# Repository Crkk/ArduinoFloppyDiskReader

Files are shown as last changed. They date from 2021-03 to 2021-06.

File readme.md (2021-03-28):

# Arduino Powered Amiga Floppy Disk Reader and Writer
Created by Robert Smith @RobSmithDev

Hardware design added by @Crkk

# What is it?
This project uses an Arduino to interface with a floppy disk drive and communicate with a PC in order to recover the data from Amiga formatted AmigaDOS disks.
It also allows you to write a backed up ADF file back onto a floppy disk!

# ArduinoFloppyReader
This Visual Studio 2017 project contains two applications, a command line, and a Windows dialog based application

# FloppyDriverController.sketch
This is the Ardunio source code/sketch

# AVR Firmware
If you want to use the AVR directly instead of within the Arduino environment, then jump to [https://github.com/jtsiomb/usbamigafloppy] where John Tsiombikas has ported the code.

# Help and Instructions 
For further details including how to wire this up please visit [http://amiga.robsmithdev.co.uk]

# Whats changed?
V2.2 Fixed 99% of checksum errors when writing by erasing the track first
V2.1 Diagnostics and potential write bug fixed
V2.0 Disk reading has been vastly improved and you can now also write disks!
V1.0 Initial release, can read disks fairly well

# Licence
This entire project is available under the GNU General Public License v3 licence.  See licence.txt for more details.

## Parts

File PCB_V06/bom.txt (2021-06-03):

100 nF 50V	C1, C2, C6		0603
1 kOhm		R1, R2			0603
220 Ohm		R3, R4			0603
22 uF 25V	C3, C4, C5, C7, C8, C9	0805
ATMEGA328P	U1			TQFP32
FT232RL		IC1			SSOP28
16MHz resonator Y1			3.2x1.3
Mini USB	USB			B-SMT
Green LED	D1			5mm
Red LED		D2			5mm
Header		FLOPPY			34pin male
FPC conn	FLOPPY_26		26pin 1mm

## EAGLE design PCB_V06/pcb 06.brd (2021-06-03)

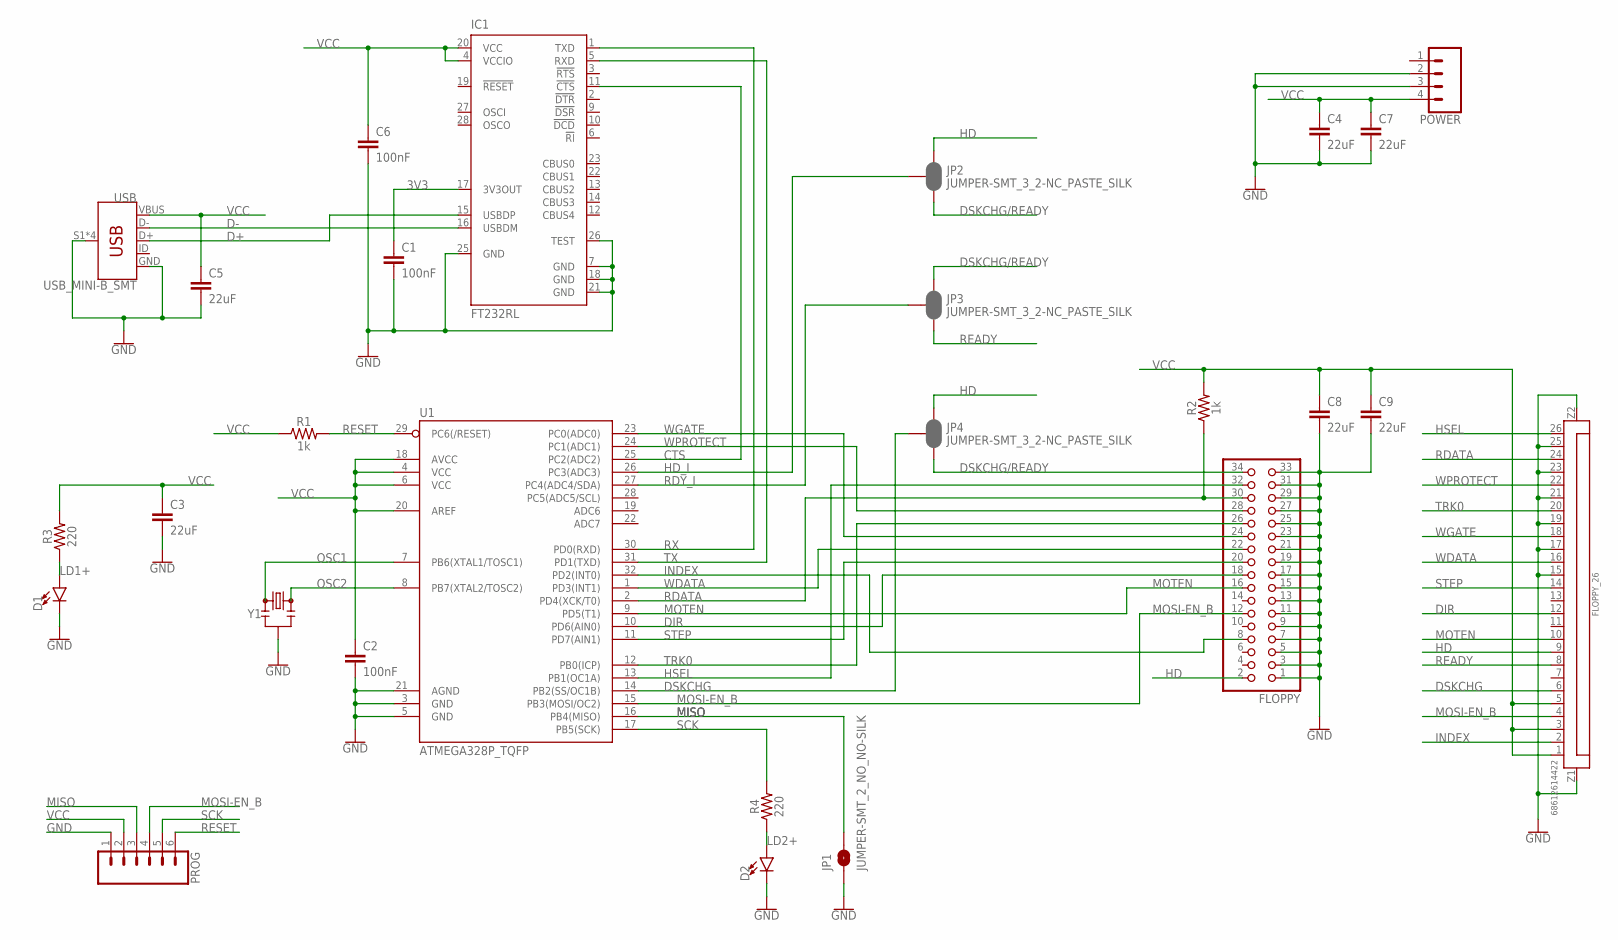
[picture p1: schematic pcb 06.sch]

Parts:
C1, C2, C6: 100nF; 0603
C3, C4, C5, C7, C8, C9: 22uF; C0805
D1, D2: LED5MM; LED_5MM
FLOPPY: PINHD-2X17_2.54-90°; 2X17/90
FLOPPY_26: 68612614422
IC1: FT232RL; SSOP28
JP1: JUMPER-SMT_2_NO_NO-SILK; SMT-JUMPER_2_NO_NO-SILK
JP2, JP3, JP4: JUMPER-SMT_3_2-NC_PASTE_SILK; SMT-JUMPER_3_2-NC_PASTE_SILK
POWER: CONN_04; 1X04
PROG: CONN_06SILK_FEMALE_PTH; 1X06
R1, R2: 1k; 0603
R3, R4: 220; 0603
U1: ATMEGA328P_TQFP; TQFP32-08
USB: USB_MINI-B_SMT; USB-MINIB
Y1: RESONATORSMD-3.2X1.3; RESONATOR-SMD-3.2X1.3

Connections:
3V3: C1.1, IC1.17 (3V3OUT)
CTS: IC1.11 (!CTS), U1.25 (PC2(ADC2))
D+: IC1.15 (USBDP), USB.D+
D-: IC1.16 (USBDM), USB.D-
DIR: FLOPPY.18, FLOPPY_26.12, U1.10 (PD6(AIN0))
DSKCHG: FLOPPY_26.6, JP4.2, U1.14 (PB2(SS/OC1B))
DSKCHG/READY: FLOPPY.34, JP2.3, JP3.1, JP4.3
GND: C1.2, C2.2, C3.2, C4.2, C5.2, C6.2, C7.2, C8.2, C9.2, D1.K (C), D2.K (C), FLOPPY.1, FLOPPY.3, FLOPPY.5, FLOPPY.7, FLOPPY.9, FLOPPY.11, FLOPPY.13, FLOPPY.15, FLOPPY.17, FLOPPY.19, FLOPPY.21, FLOPPY.23, FLOPPY.25, FLOPPY.27, FLOPPY.29, FLOPPY.31, FLOPPY.33, FLOPPY_26.15, FLOPPY_26.17, FLOPPY_26.19, FLOPPY_26.21, FLOPPY_26.23, FLOPPY_26.25, FLOPPY_26.Z1, FLOPPY_26.Z2, IC1.7 (GND), IC1.18 (GND), IC1.21 (GND), IC1.25 (GND), IC1.26 (TEST), JP1.1, POWER.2, POWER.3, PROG.1, U1.3 (GND), U1.5 (GND), U1.21 (AGND), USB.GND, USB.S1 (SHIELD), USB.S2 (SHIELD), USB.S3 (SHIELD), USB.S4 (SHIELD), Y1.2
HD: FLOPPY.2, FLOPPY_26.9, JP2.1, JP4.1
HD_I: JP2.2, U1.26 (PC3(ADC3))
HSEL: FLOPPY.32, FLOPPY_26.26, U1.13 (PB1(OC1A))
INDEX: FLOPPY.8, FLOPPY_26.2, U1.32 (PD2(INT0))
LD1+: D1.A, R3.1
LD2+: D2.A, R4.1
MISO: JP1.2, PROG.3, U1.16 (PB4(MISO))
MOSI-EN_B: FLOPPY.12, FLOPPY_26.4, PROG.4, U1.15 (PB3(MOSI/OC2))
MOTEN: FLOPPY.16, FLOPPY_26.10, U1.9 (PD5(T1))
OSC1: U1.7 (PB6(XTAL1/TOSC1)), Y1.1
OSC2: U1.8 (PB7(XTAL2/TOSC2)), Y1.3
RDATA: FLOPPY.30, FLOPPY_26.24, R2.1, U1.2 (PD4(XCK/T0))
RDY_I: JP3.2, U1.27 (PC4(ADC4/SDA))
READY: FLOPPY_26.8, JP3.3
RESET: PROG.6, R1.2, U1.29 (PC6(/RESET))
RX: IC1.1 (TXD), U1.30 (PD0(RXD))
SCK: PROG.5, R4.2, U1.17 (PB5(SCK))
STEP: FLOPPY.20, FLOPPY_26.14, U1.11 (PD7(AIN1))
TRK0: FLOPPY.26, FLOPPY_26.20, U1.12 (PB0(ICP))
TX: IC1.5 (RXD), U1.31 (PD1(TXD))
VCC: C2.1, C3.1, C4.1, C5.1, C6.1, C7.1, C8.1, C9.1, FLOPPY_26.1, FLOPPY_26.3, FLOPPY_26.5, IC1.4 (VCCIO), IC1.20 (VCC), POWER.4, PROG.2, R1.1, R2.2, R3.2, U1.4 (VCC), U1.6 (VCC), U1.18 (AVCC), U1.20 (AREF), USB.VBUS
WDATA: FLOPPY.22, FLOPPY_26.16, U1.1 (PD3(INT1))
WGATE: FLOPPY.24, FLOPPY_26.18, U1.23 (PC0(ADC0))
WPROTECT: FLOPPY.28, FLOPPY_26.22, U1.24 (PC1(ADC1))

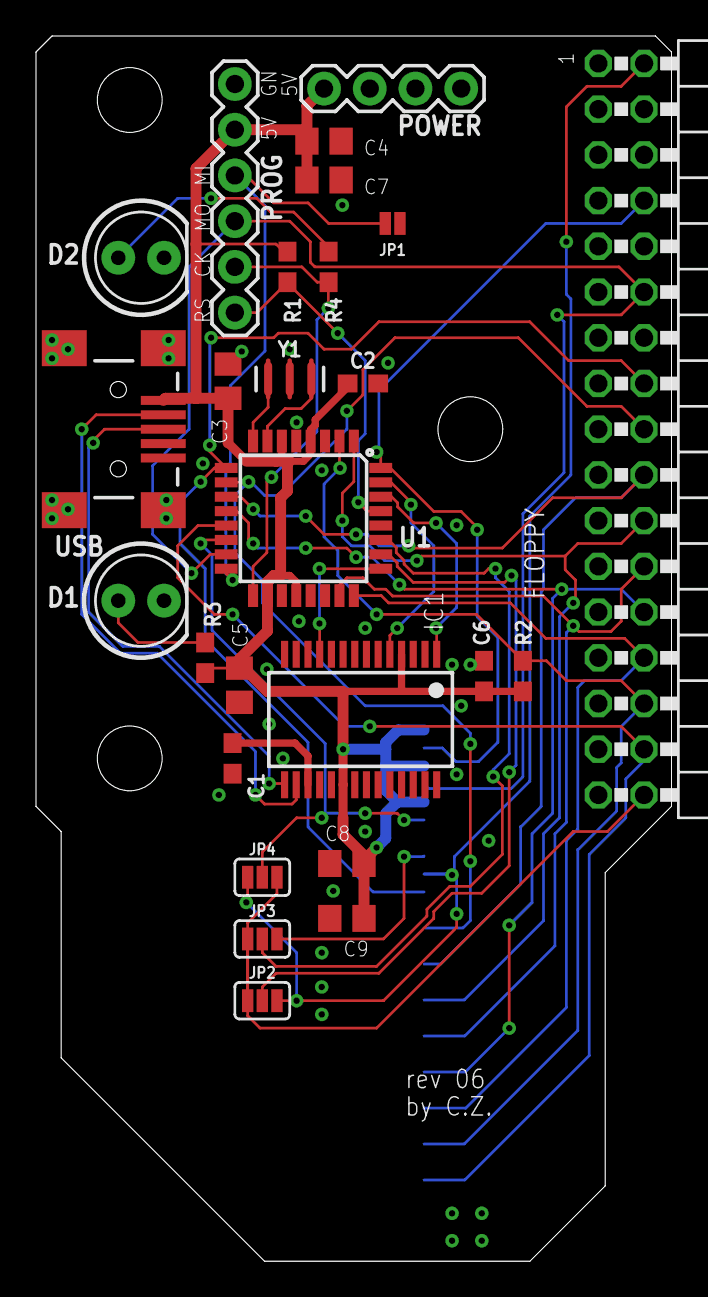
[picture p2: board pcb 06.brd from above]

Board: 2 copper layers, 35.3 x 68.1 mm, 27 parts (1 on the bottom side), 32 nets.

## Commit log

2020-10-22 Update ArduinoInterface.cpp
    typo fix
2021-06-03 Rename pcb 000.brd to pcb 06.brd
    [pcb 06.brd]
2021-06-03 Rename pcb 000.sch to pcb 06.sch
    [pcb 06.sch]

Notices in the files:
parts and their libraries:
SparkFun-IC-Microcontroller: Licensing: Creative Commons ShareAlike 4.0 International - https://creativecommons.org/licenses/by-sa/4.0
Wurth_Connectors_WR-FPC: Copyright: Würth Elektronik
